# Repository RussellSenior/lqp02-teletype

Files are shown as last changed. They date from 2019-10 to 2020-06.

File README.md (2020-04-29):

This is a project motivated by a desire to create a daisywheel teletype, to give a
similar experience to that of a Model 33ASR teletype, but with upper and lowercase
characters. Thanks to Hugh Pyle and his fantastic [Twitch channel](https://www.twitch.tv/33asr) for the
inspiration.  Thanks also to Chris Gregg and his project:
https://github.com/tofergregg/IBM-Wheelwriter-Hack and to this very similar project
by Stephen Casner: https://github.com/IBM-1620/Junior.

The goal is to intercept user input from the keyboard and send it to a remote computer
and receive the echoed characters from the remote computer and send the corresponding
commands to the printing mechanism for hardcopy output.

I obtained an IBM Wheelwriter 5 from the Tektronix Surplus Store (open two days a month,
first and third Thursdays, from 2pm to 4pm) on the Beaverton Oregon campus of Tektronix.
This typewriter came with the PC Printer option, which hangs on the back of the case
and interfaces by a 6 (or 7?) pin bus. The cost of the typewriter was $25. I purchased
two new-in-box ribbon cartridges from the same location for $0.50 each.

In the process of working on the IBM Wheelwriter, I was given a couple of DEC LQP02 serial
daisywheel printers. This repository reflects the work on the LQP02.  These have some advantages,
including the availability of a native RS-232 interface and full ASCII character set wheels.

This project uses a Teensy 3.1 with a PS/2 keyboard, and two serial ports.  One serial port
talks to the printer and the other talks to a remote computer.  It decodes keyboard events using
the Ps2KeyboardHost library from Steve Benz: https://github.com/SteveBenz/PS2KeyboardHost,
sends them to the remote computer, reads data coming from the remote computer and sends them
to the printer's serial port.

The printer is constrained in the rate at which it can turn bytes into print, so flow control
is important. It turns out that the printer does XON/XOFF flow control, and the remote computer
does RTS/CTS hardware flow control, so the Teensy program looks for XON/XOFF from the printer
and stops reading from the computer serial port when it last saw XOFF, which lets the hardware
UART's flow control just work.

One of the disadvantages of the LQP02 is that it was intended as a strictly output device, and
as a result being able to see what you are typing is not prioritized.  I saw a video on youtube
(https://www.youtube.com/watch?v=TRxz4x45i54) which used the vertical motion control to roll
the platen to lift the active printing line up above the printing mechanism at appropriate
moments so that you can see what you have typed.  On the LQP02, 12 lines seems about right.
When rolling the paper back down to continue printing, I am rolling an extra line down and then
back up one to hopefully improve vertical registration.  Thanks Blake Thomas for the idea.

The other disadvantage is that the LQP02 prints bi-directionally, which means that it needs
to pause on input to see if more input is coming. If there is, then it can effectively read
ahead and see the opportunity to print backwards. This introduces an annoying lag between input
and when the characters are struck. So far, no means of turning off this delay has been found.

There are a bunch of TODO's:

 * Add a toggle switch to switch between Line and Local mode;
 * Support the mini-DIN8 connected Sun Keyboard;
 * Support output to an IBM Wheelwriter;

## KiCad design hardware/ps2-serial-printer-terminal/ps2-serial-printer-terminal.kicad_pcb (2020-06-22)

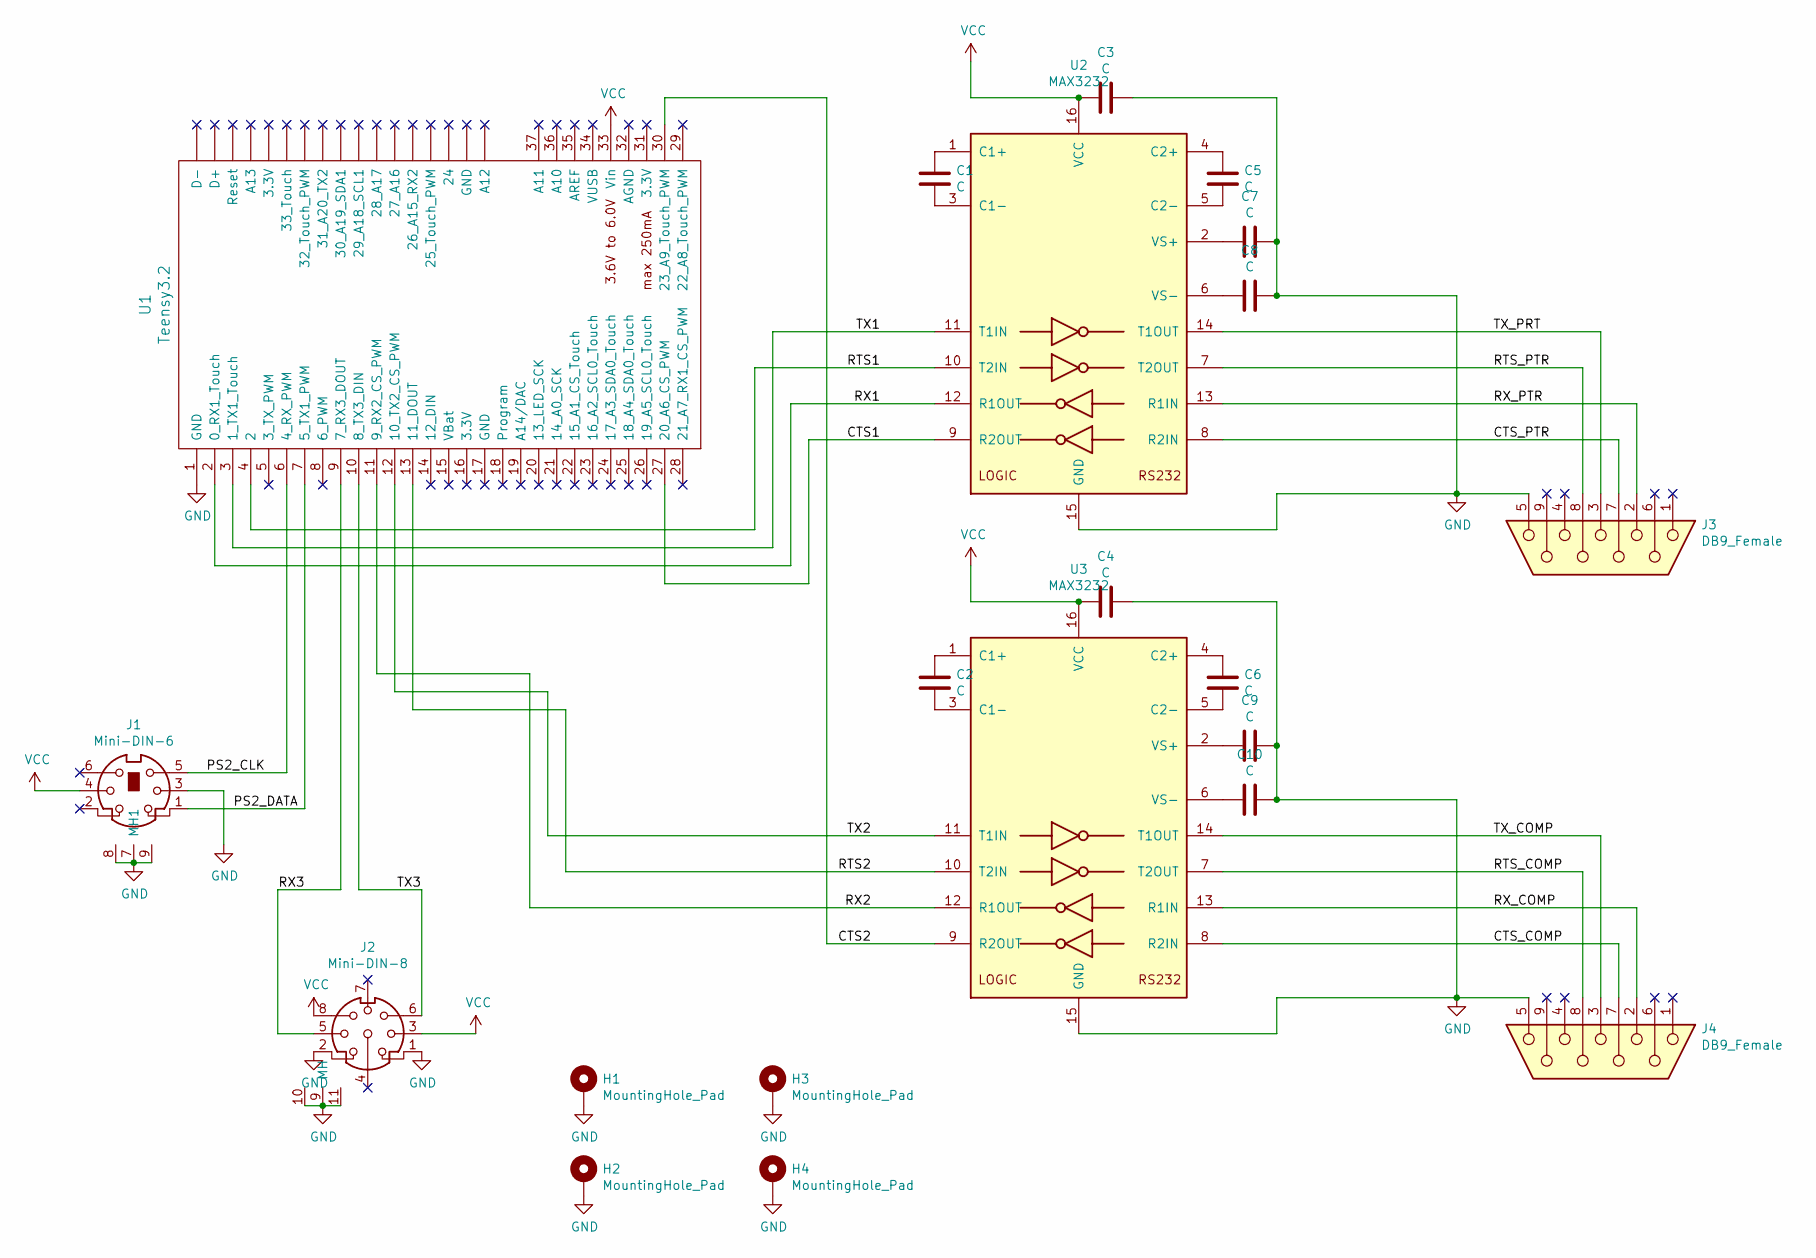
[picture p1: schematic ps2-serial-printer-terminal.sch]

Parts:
C1, C2, C3, C4, C5, C6, C7, C8, C9, C10: C; C_0805_2012Metric_Pad1.15x1.40mm_HandSolder
H1, H2, H3, H4: MountingHole_Pad; MountingHole_3mm_Pad_Via
J1: Mini-DIN-6; 5749231-1
J2: Mini-DIN-8; MD-80SM
J3, J4: DB9_Female; DSUB-9_Female_Horizontal_P2.77x2.84mm_EdgePinOffset14.56mm_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
U1: Teensy3.2; Teensy30_31_32_LC_minus
U2, U3: MAX3232; SOIC-16_3.9x9.9mm_P1.27mm

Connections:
/CTS1: U1.27 (20_A6_CS_PWM), U2.9 (R2OUT)
/CTS2: U1.30 (23_A9_Touch_PWM), U3.9 (R2OUT)
/CTS_COMP: J4.7, U3.8 (R2IN)
/CTS_PTR: J3.7, U2.8 (R2IN)
/PS2_CLK: J1.5, U1.6 (4_RX_PWM)
/PS2_DATA: J1.1, U1.7 (5_TX1_PWM)
/RTS1: U1.4 (2), U2.10 (T2IN)
/RTS2: U1.13 (11_DOUT), U3.10 (T2IN)
/RTS_COMP: J4.8, U3.7 (T2OUT)
/RTS_PTR: J3.8, U2.7 (T2OUT)
/RX1: U1.2 (0_RX1_Touch), U2.12 (R1OUT)
/RX2: U1.11 (9_RX2_CS_PWM), U3.12 (R1OUT)
/RX3: J2.5, U1.9 (7_RX3_DOUT)
/RX_COMP: J4.2, U3.13 (R1IN)
/RX_PTR: J3.2, U2.13 (R1IN)
/TX1: U1.3 (1_TX1_Touch), U2.11 (T1IN)
/TX2: U1.12 (10_TX2_CS_PWM), U3.11 (T1IN)
/TX3: J2.6, U1.10 (8_TX3_DIN)
/TX_COMP: J4.3, U3.14 (T1OUT)
/TX_PRT: J3.3, U2.14 (T1OUT)
GND: C3.1, C4.1, C7.1, C8.1, C9.1, C10.1, H1.1, H2.1, H3.1, H4.1, J1.3, J1.7 (MH1), J1.8, J1.9, J2.1, J2.2, J2.9 (MH), J2.10, J2.11, J3.5, J4.5, U1.1 (GND), U2.15 (GND), U3.15 (GND)
unnamed: C1.1, U2.1 (C1+)
unnamed: C1.2, U2.3 (C1-)
unnamed: C2.1, U3.1 (C1+)
unnamed: C2.2, U3.3 (C1-)
unnamed: C5.1, U2.4 (C2+)
unnamed: C5.2, U2.5 (C2-)
unnamed: C6.1, U3.4 (C2+)
unnamed: C6.2, U3.5 (C2-)
unnamed: C7.2, U2.2 (VS+)
unnamed: C8.2, U2.6 (VS-)
unnamed: C9.2, U3.2 (VS+)
unnamed: C10.2, U3.6 (VS-)
VCC: C3.2, C4.2, J1.4, J2.3, J2.8, U1.33 (Vin), U2.16 (VCC), U3.16 (VCC)

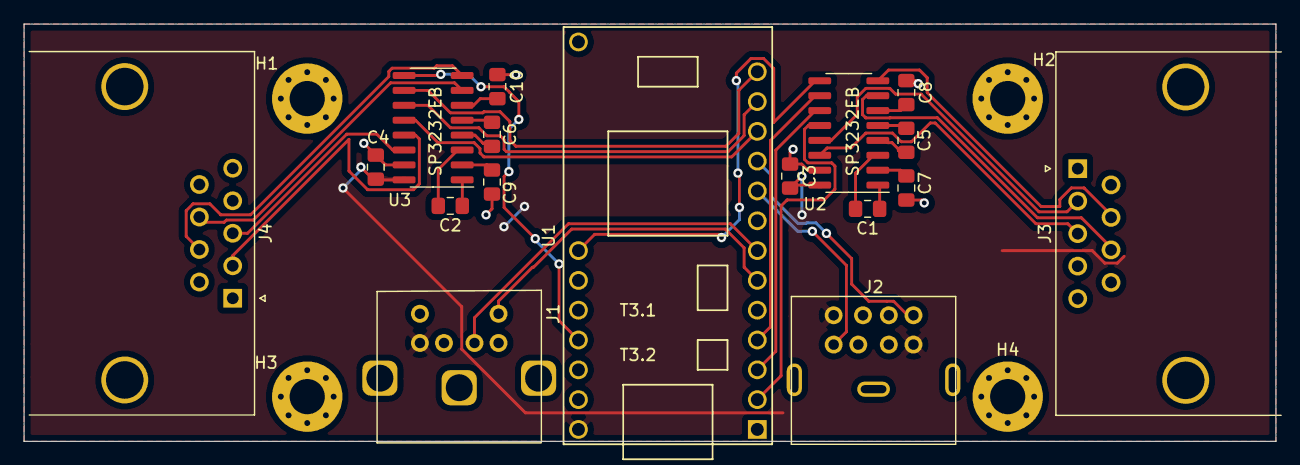
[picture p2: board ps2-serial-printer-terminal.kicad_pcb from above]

Board: 2 copper layers, 106.7 x 35.6 mm, 21 parts (0 on the bottom side), 34 nets.

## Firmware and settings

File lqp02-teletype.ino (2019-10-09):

#include "ps2_Keyboard.h"
#include "ps2_NeutralTranslator.h"
#include "ps2_SimpleDiagnostics.h"
// #include "ps2_KeyboardLeds.h"

#define Printer Serial1
#define Computer Serial2
#define Sun Serial3

#define ESCAPE  0x1B

// PS/2 keyboard interface
static const int clockPin = 4;
static const int dataPin = 5;

bool debug = 1;
bool local = 0;
bool rolledUp = 0;
int linesToRoll = 12;

int rollUpToShow() {
    if(!rolledUp) {
        Printer.printf("%c[16t",ESCAPE); // reset line 1 to current line (don't do a form feed! :)
        Printer.printf("%c[%de",ESCAPE,linesToRoll);
        rolledUp = 1;
    }
    return 0;
}

int rollDownToPrint() {
    if(rolledUp) {
        Printer.printf("%c[%dk",ESCAPE,linesToRoll);
        rolledUp = 0;
    }
    return 0;
}

int sendEscapeSequence(int f) {
    Serial.printf("sending escape sequence %d\n",f);
    switch(f) {
        case 1: // reset printer
            Printer.printf("%cc",ESCAPE);
            Printer.printf("%c[11l",ESCAPE);
            break;
        case 2: // advance paper to next line
            Printer.printf("%cE",ESCAPE);
            break;
        case 3: // set right margin wrap mode
            Printer.printf("%c[?7h",ESCAPE);
            break;
        case 4: // reset right margin wrap mode
            Printer.printf("%c[?7l",ESCAPE);
            break;
        case 5: // enter new line mode
            Printer.printf("%c[20h",ESCAPE);
            break;
        case 6: // reset new line mode
            Printer.printf("%c[20l",ESCAPE);
            break;
        case 7: // set 8 column tabs
            Printer.printf("%c[9;17;25;33;41;49;57;65;73;81u",ESCAPE);
            break;
        case 8: // unset column tabs
            Printer.printf("%c[3g",ESCAPE);
            break;
        case 9: // set 15 char/inch
            Printer.printf("%c[90;48 G",ESCAPE);
            break;
        case 10: // form feed
            Printer.printf("%c",0x0c);
            break;
        case 11: // line feed
            Printer.printf("%cD",ESCAPE);
            break;
        case 12: // reverse line feed
            Printer.printf("%cM",ESCAPE);
            break;
        default: return -1;
    }
    return 0;
}


int16_t unshiftTable[70] = {
  0x7F, 0x1B, 0x08, 0x09, 0x0A, 0x20, 
  0x30, 0x31, 0x32, 0x33, 0x34, 0x35, 0x36, 0x37, 0x38, 0x39,
  0x2E, 0x0A, 0x2B, 0x2D, 0x2A, 0x2F,
  0x30, 0x31, 0x32, 0x33, 0x34, 0x35, 0x36, 0x37, 0x38, 0x39,
  0x27, 0x2C, 0x2D, 0x2E, 0x2F, -1,
  0x60, 0x61, 0x62, 0x63, 0x64, 0x65, 0x66, 0x67, 0x68, 0x69,
  0x6A, 0x6B, 0x6C, 0x6D, 0x6E, 0x6F,
  0x70, 0x71, 0x72, 0x73, 0x74, 0x75, 0x76, 0x77, 0x78, 0x79,
  0x7A, 0x3B, 0x5C, 0x5B, 0x5D, 0x3D
};

int16_t shiftTable[70] = {
  0x7F, 0x1B, 0x08, -1, 0x0A, 0x20, 
  -1, -1, -1, -1, -1, -1, -1, -1, -1, -1,
  -1, -1, -1, -1, -1, -1,
  0x29, 0x21, 0x40, 0x23, 0x24, 0x25, 0x5E, 0x26, 0x2A, 0x28,
  0x22, 0x3C, 0x5F, 0x3E, 0x3F, -1,
  0x7E, 0x41, 0x42, 0x43, 0x44, 0x45, 0x46, 0x47, 0x48, 0x49,
  0x4A, 0x4B, 0x4C, 0x4D, 0x4E, 0x4F,
  0x50, 0x51, 0x52, 0x53, 0x54, 0x55, 0x56, 0x57, 0x58, 0x59,
  0x5A, 0x3A, 0x7C, 0x7B, 0x7D, 0x2B
};

int16_t keycode2ascii(uint16_t c) {
    // check for special bits so we can bail
    if (c & ~0x607F) {
        return -1;
    }

    if (!(c & 0x2000)) {
        int d = (c & 0x7f) - 0x1A;
        if (d > 0x46 && d <= 0x52) { // I'm a function key
            sendEscapeSequence(c - 0x60);
        }
        if (d >= 0 && d < sizeof(shiftTable)) {
            if (c & 0x4000) {
                return shiftTable[d];
            } else {
                return unshiftTable[d];
            }
        } 
    } else {
    // handle CTRL
        // for CTRL-letter, nuke shift bit
        if ((c & 0xFF) >= 0x41 && (c & 0xFF) <= 0x5A) {
            c = c & ~0x4000; 
        }
        if (c >= 0x2041 && c <= 0x205A) {
            return c & 0x1F;
        }
        switch (c) {
            case 0x6032: // ^@
                return 0;
            case 0x205D: // ^[
                return 0x1B;
            case 0x205C: // ^BACKSLASH
                return 0x1C;
            case 0x205E: // ^]
                return 0x1D;
            case 0x6036: // ^^
                return 0x1E;
            case 0x603C: // ^_
                return 0x1F;
        }
    }
    return -1;
}


typedef ps2::SimpleDiagnostics<32> Diagnostics;
static Diagnostics diagnostics;
static ps2::Keyboard<dataPin,clockPin,16,Diagnostics> ps2Keyboard(diagnostics);

void setup() {
    pinMode(LED_BUILTIN, OUTPUT);
    ps2Keyboard.begin();
    Printer.begin(9600,SERIAL_7E1);
    Printer.attachRts(2);
    Printer.attachCts(20);
    sendEscapeSequence(1); // reset
    sendEscapeSequence(7); // set tabstops
    sendEscapeSequence(9); // set 15 chars/inch 8 lines/inch
    Computer.begin(1200,SERIAL_8N1);
    Computer.attachRts(11);
    Computer.attachCts(23);
    Sun.begin(1200,SERIAL_8N1);
}

static ps2::NeutralTranslator translator;
bool pxon = 1;

bool timedBefore = 0;
unsigned long lastPrint = 0;


void loop() {
    // diagnostics.setLedIndicator<LED_BUILTIN, ps2::DiagnosticsLedBlink::heartbeat>();
    int fromComputer;
    int fromPrinter;
    unsigned long sinceLastPrint = millis() - lastPrint;

    if (timedBefore && sinceLastPrint > 500) {
        rollUpToShow();
    }

    if (Computer.available() > 0 && pxon) {
        fromComputer = Computer.read();
        if (!local) {
            rollDownToPrint();
            Printer.write(fromComputer);
            lastPrint = millis();
            timedBefore = 1;
        }
        if (debug) {
           Serial.printf("computer: 0x%02x %c\n",fromComputer,fromComputer);
        }
    }
    if (Printer.available() > 0) {
        fromPrinter = Printer.read();
        fromPrinter &= 0x7F;
        switch (fromPrinter) {
            case 0x13:
                pxon = 0;
                break;
            case 0x11:
                pxon = 1;
                break;
        }
        Serial.printf("printer: 0x%02x %c\n",fromPrinter,fromPrinter);
    }

    if (Sun.available() > 0) {
        unsigned int fromSun;
        fromSun = Sun.read();
        if (debug) {
            Serial.printf("sunkbd: 0x%02x\n",fromSun);
        }
    }

    ps2::KeyboardOutput scanCode = ps2Keyboard.readScanCode();
    if (scanCode != ps2::KeyboardOutput::none) {
        // Serial.printf("kbd_scan = %0x\n",scanCode);
        ps2::KeyCode translated = translator.translatePs2Keycode(scanCode);
        if (translated != ps2::KeyCode::PS2_NONE) {
            int c = keycode2ascii(translated);
            if (c >= 0) {
                if (debug) {
                Serial.printf("keyboard: 0x%02x %c\n",c,c);
                }

                if (!local) {
                    Computer.write(c);
                } else {
                    Printer.write(c);
                }
            }
        }
    }
}

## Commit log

2019-05-12 first version with working flow control
2019-05-18 add a form feed, line feed and reverse line feed to function keys
    [lqp02-teletype.ino]
2019-05-18 add a feature to show text hidden by printing mechanism
    After 500ms of printing inactivity, roll platen up N lines (currently 8)
    to show state to user. Before printing again, roll platen back down N+1,
    then up one to return to the current location for new printing. This
    enhances the experience for the user, as they can see what they just typed
    or what the computer just typed back at them.
2019-10-09 correct incorrect mapping of the right paren key
    [lqp02-teletype.ino]
2020-06-22 render prototype circuit in kicad
    [ps2-serial-printer-terminal-v0.kicad_pcb, ps2-serial-printer-terminal.kicad_pcb, ps2-serial-printer-terminal.sch]
